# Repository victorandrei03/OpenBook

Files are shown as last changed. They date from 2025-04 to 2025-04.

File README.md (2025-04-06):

# OpenBook - 331CC Preda Victor-Andrei

## 📋 Descriere Proiect
Acest proiect reprezintă o placă electronică (e-board) customizată, proiectată în Autodesk Fusion 360. Include:
- Schematică completă
- Design PCB
- Design 3D al carcasei
- Listă completă de componente (BOM)

## 🗂️ Diagrama bloc



## 🛠️ Componente Cheie
| Componentă | Model | Descriere |
|---|---|---|
| **Microcontroler** | ESP32-C6-WROOM-1-N8 | MCU principal cu WiFi/Bluetooth LE |
| **Ceas RTC** | DS3231SN# | Ceas în timp real cu compensare de temperatură |
| **Senzori** | BME680 | Senzor ambiental (temperatură, umiditate, presiune, VOC) |
| **Management Power** | BD5229G-TR + MCP73831 | Sistem complet de încărcare baterii |

## 📊 Bill of Materials (BOM)

### 🔌 Conectori & Interfețe
| Part Name | Device | Link |
|---|---|---|
| J1 | FH34SRJ-24S-0.5SH_99_ | [Datasheet](https://componentsearchengine.com/part-view/XC6220A331MR-G/Torex) |
| J2 | USB4110-GF-A | [Mouser](https://componentsearchengine.com/part-view/USB4110-GF-A/GCT) |
| J3 | QWIIC_CONNECTORJS-1MM | [SparkFun](https://www.sparkfun.com/products/14417) |

### 💾 Memorie & Storage
| Part Name | Device | Link |
|---|---|---|
| U1 | W25Q512JVEIQ | [Winbond](https://www.snapeda.com/parts/W25Q512JVEIQ/Winbond+Electronics/view-part/) |

### ⚡ Power Management
| Part Name | Device | Link |
|---|---|---|
| IC1 | BD5229G-TR | [ROHM](https://componentsearchengine.com/part-view/BD5229G-TR/ROHM) |
| U4 | MAX17048G+T10 | [Analog Devices](https://www.snapeda.com/parts/MAX17048G+T10/Analog+Devices/view-part/) |

### 🎚️ Componente Pasive
| Categorie | Qty | Device | Link |
|---|-----|---|---|
| **Rezistoare** | 25+ | RR0402 100K | [YAGEO](https://componentsearchengine.com/part-view/R0402%201%25%20100%20K/YAGEO) |
| **Condensatoare** | 20+ | CC0402 1µF | [YAGEO](https://componentsearchengine.com/part-view/CC0402MRX5R5BB106/YAGEO) |
| **Inductoare** | 1 | 744043680 | [Würth](https://eu.mouser.com/ProductDetail/Wurth-Elektronik/744043680) |

### 🛑 Protecții & Diodes
| Part Name | Device | Link |
|---|---|---|
| D1 | USBLC6-2SC6Y | [STMicro](https://www.snapeda.com/parts/USBLC6-2SC6Y/STMicroelectronics/view-part/) |
| D3-D5 | MBR0530 | [Mouser](https://eu.mouser.com/ProductDetail/KYOCERA-AVX/SD0805S020S1R0) |

## 🛠️ Descriere Hardware Detaliată

### 1. Microcontroller - ESP32-C6-WROOM-1-N8
**Specificații Avansate:**
- **Arhitectură:** RISC-V single-core cu 160MHz (configurabil dinamic)
- **Memorie:**
  - 320KB SRAM intern (pentru date)
  - 512KB ROM (pentru bootloader)
  - 8MB Flash SPI (W25Q512JVEIQ) - stochează firmware și date utilizator
- **Conectivitate:**
  - **WiFi 6** (802.11ax) cu throughput de până la 300Mbps
  - **Bluetooth 5 LE** cu support Mesh
  - **Zigbee 3.0** pentru IoT industrial
- **Periferice Integrate:**
  - 4× controller SPI (inclusiv Quad-SPI)
  - 2× I²C (software configurable)
  - 2× UART (cu flow control hardware)
  - 1× USB 2.0 OTG Full-Speed

**Management Energie:**
- **Moduri de operare:**
  - Active Mode: 80mA @ 160MHz
  - Light Sleep: 1.5mA (perif. RAM păstrate)
  - Deep Sleep: 20µA (doar RTC activ)
- **Feature-uri speciale:**
  - Wake-up din Deep Sleep prin:
    - GPIO
    - Timer RTC
    - UART
    - Senzor BME680 (via interrupt)
   
---

### 2. Sistem de Alimentare

**Componente Cheie:**
1. **MCP73831**
   - Curent de încărcare programabil: 100-500mA
   - Protecții integrate: Over-voltage, Reverse discharge
   - LED indicator de stare (conectat la GPIO18)

2. **BD5229G-TR**
   - Eficiență 92% @ 500mA load
   - Ripple voltage < 50mV
   - Shutdown current < 1µA

3. **MAX17048G+T10**
   - Precizie măsurare: ±1% SOC
   - Alertă baterie critică (conectat la GPIO15)
   - Consum propriu: 7µA în mod normal

---

### 3. Senzori & Periferice

#### 3.1 Senzor Environmental BME680
**Interfață:** I²C @ 400kHz (adresă 0x76)  
**Caracteristici unice:**
- **Algoritm BSEC** pentru calcul IAQ (Indice Calitate Aer)
- **Compensare automată** a variațiilor de temperatură
- **Calibrare în fabrică** pentru precizie ridicată

**Conexiuni:**
| Pin BME680 | Pin ESP32 | Notă |
|---|---|---|
| VDD | 3.3V | Alimentare filtrată |
| GND | GND | - |
| SDA | GPIO1 | Cu pull-up 4.7kΩ |
| SCL | GPIO2 | Cu pull-up 4.7kΩ |

#### 3.2 Real-Time Clock DS3231SN#
**Precizie:** ±2ppm (echiv. ~1min/an)  
**Backup:** Supercondensator CPH3225A (10F @ 3.3V)  
**Funcționalități:**
- Alarmă programabilă
- Output square wave (1Hz-32kHz)
- Temperatură internă compensată

---

### 4. Interfețe Externe

#### 4.1 Port USB-C
**Implementare:**
- **Controler:** USB PHY integrat în ESP32-C6
- **Protecții:**
  - ESD: USBLC6-2SC6Y (8kV IEC61000-4-2)
  - Current limit: Polyfuse 500mA

**Funcționalități:**
1. Încărcare baterie
2. Serial Console (CDC-ACM)
3. Update firmware (DFU mode)

#### 4.2 Conector Qwiic
**Aplicații:**
- Conectare senzori adiționali
- Debug I²C bus
- Extensii custom

---

## 🔌 Mapare Pini ESP32-C6

| Pin ESP32-C6 | Componentă / Semnal | Motivul Alegerii |
|---|---|---|
| **GPIO1 (SDA)** | Magistrală I²C (BME680, MAX17048, DS3231) | Permite comunicarea simultană cu multiple dispozitive prin protocol standard |
| **GPIO2 (SCL)** | Semnal de sincronizare I²C | Asigură temporizarea corectă a transferurilor pe magistrala shared I²C |
| **GPIO5** | SPI MISO (E-Paper) | Facilitatează recepția datelor de stare de la display |
| **GPIO6** | SPI MOSI (E-Paper) | Canal dedicat pentru transmiterea imaginilor către ecran |
| **GPIO7** | SPI CLK (E-Paper) | Generează semnalul de ceas pentru sincronizarea datelor SPI |
| **GPIO8** | SPI CS (E-Paper) | Selectează exclusiv display-ul în configurații multi-slave |
| **GPIO9** | E-Paper DC | Determină dacă transferul conține date sau comenzi |
| **GPIO10** | E-Paper RST | Permite resetarea hardware a display-ului în caz de eroare |
| **GPIO11** | E-Paper BUSY | Monitorizează starea de ocupat pentru sincronizare fără polling |
| **GPIO12** | BUTTON_BOOT | Configurat special pentru intrare în modul de programare |
| **GPIO13** | BUTTON_RESET | Asigură resetarea controlată a sistemului |
| **GPIO14** | BUTTON_USER | Permite interacțiunea utilizatorului cu meniul principal |
| **GPIO15** | MAX17048 ALERT | Semnalează stări critice ale bateriei prin interrupt |
| **GPIO16** | USB D+ | Implementare directă a fizicului USB conform specificației |
| **GPIO17** | USB D- | Pereche diferențială obligatorie pentru comunicarea USB |
| **GPIO18** | STATUS_LED | Oferă feedback vizual despre starea sistemului |
| **GPIO19** | SD Card CS | Selectează cardul SD în arhitectura SPI shared |
| **GPIO20** | SD Card MISO | Primește date de la memoria externă |
| **GPIO21** | SD Card MOSI | Transmite comenzi și date către cardul SD |
| **GPIO4** | SD Card CLK | Asigură sincronizarea transferurilor SPI către/storage |

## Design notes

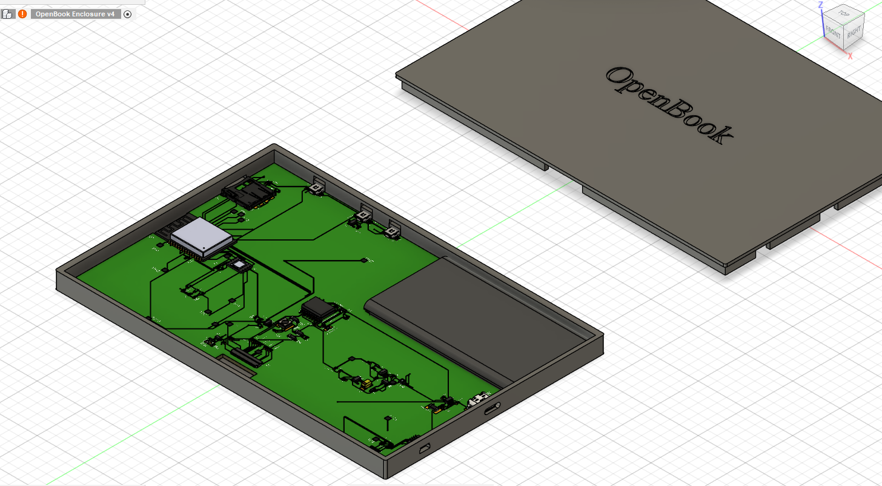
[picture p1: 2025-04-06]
Images/openbook_3D.png

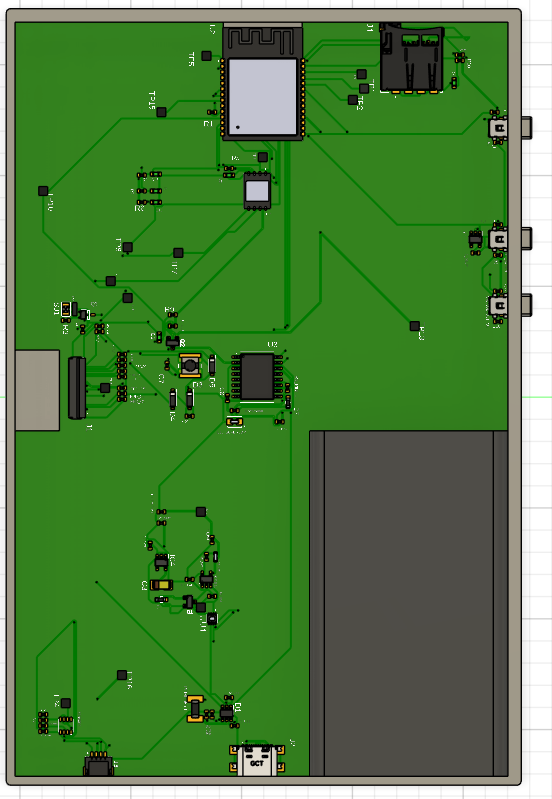
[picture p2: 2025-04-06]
Images/openbook_top.png

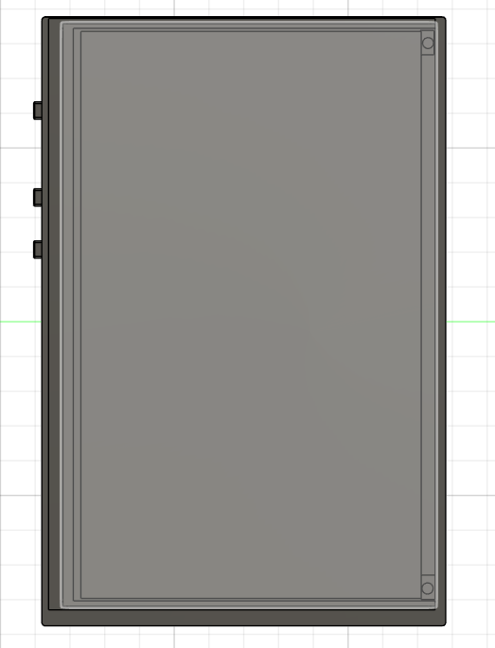
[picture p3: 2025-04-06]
Images/openbook_bot.png

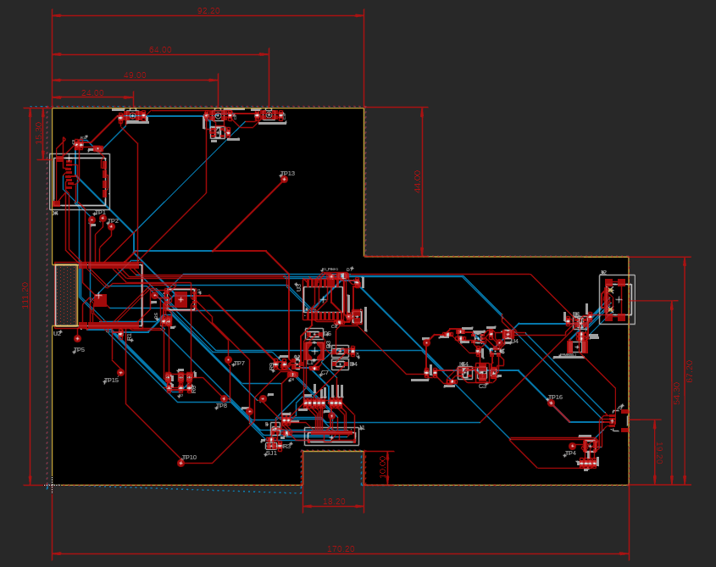
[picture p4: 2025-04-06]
Images/PCB.png

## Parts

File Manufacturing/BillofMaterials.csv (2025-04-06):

Qty | Value | Device | Package | Parts | Description | ARROW_PART_NUMBER | ARROW_PRICE-STOCK | AVAILABILITY | CENTROID_NOT_SPECIFIED | CHECK_PRICES | COPYRIGHT | DATASHEET | DESCRIPTION | DIGIKEY_DESCRIPTION | DIGIKEY_PART_NUMBER | HEIGHT | LEAD_FREE | MANUFACTURER_NAME | MANUFACTURER_PART_NUMBER | MF | MFR_NAME | MOUSER_PART_NUMBER | MOUSER_PRICE-STOCK | MOUSER_TESTING_PART_NUMBER | MOUSER_TESTING_PRICE-STOCK | MP | MPN | PACKAGE | POPULARITY | PREFIX | PRICE | PROD_ID | PURCHASE-URL | ROHS | SNAPEDA_LINK | SPICEMODEL | SPICEPREFIX | TEMPERATURE_RANGE_HIGH | TEMPERATURE_RANGE_LOW | TP_SIGNAL_NAME | VALUE
1 |  | ADAFRUIT_LEDCHIP-LED0603 | ADAFRUIT_CHIP-LED0603 | CHG_LED | LED
1 |  | SJ | SJ | SJ1 | SMD solder JUMPER |  |  |  |  |  |  |  |  |  |  |  |  |  |  |  |  |  |  |  |  |  |  |  | 3
1 | 0.1uF/50V | EAGLE-LTSPICE_CC0402 | EAGLE-LTSPICE_C0402 | EPD_C5 | CAPACITOR, European symbol |  |  |  |  |  |  |  |  |  |  |  |  |  |  |  |  |  |  |  |  |  |  |  |  |  |  |  |  |  |  | NONE | C
1 | 0.47 | ESP32_WROVER_EAGLE-LTSPICE_RR0402 | ESP32_WROVER_EAGLE-LTSPICE_R0402 | R3 | RESISTOR, European symbol |  |  |  |  |  |  |  |  |  |  |  |  |  |  |  |  |  |  |  |  |  |  |  |  |  |  |  |  |  |  | NONE | R
8 | 100nF | EAGLE-LTSPICE_CC0402 | EAGLE-LTSPICE_C0402 | C1, C2, C4_USB, C6, C8, C9, C10, C_DELAY | CAPACITOR, European symbol |  |  |  |  |  |  |  |  |  |  |  |  |  |  |  |  |  |  |  |  |  |  |  |  |  |  |  |  |  |  | NONE | C
1 | 100uF | RCL_CPOL-EUCT3528 | RCL_CT3528 | C3 | POLARIZED CAPACITOR, European symbol |  |  |  |  |  |  |  |  |  |  |  |  |  |  |  |  |  |  |  |  |  |  |  | 0 |  |  |  |  |  |  |  | C
16 | 10K | ESP32_WROVER_EAGLE-LTSPICE_RR0402 | ESP32_WROVER_EAGLE-LTSPICE_R0402 | R1_PINH, R1_PINH1, R1_PWRUSB, R2_PINH, R2_PINH1, R4, R5, R6, R7, R8, R9, R10, R_BOOT, R_CHANGE, R_CL1, R_RESET | RESISTOR, European symbol |  |  |  |  |  |  |  |  |  |  |  |  |  |  |  |  |  |  |  |  |  |  |  |  |  |  |  |  |  |  | NONE | R
1 | 10k | ESP32_WROVER_EAGLE-LTSPICE_RR0402 | ESP32_WROVER_EAGLE-LTSPICE_R0402 | R1 | RESISTOR, European symbol |  |  |  |  |  |  |  |  |  |  |  |  |  |  |  |  |  |  |  |  |  |  |  |  |  |  |  |  |  |  | NONE | R
1 | 10uF | ESP32_WROVER_EAGLE-LTSPICE_CC0402 | ESP32_WROVER_EAGLE-LTSPICE_C0402 | C7 | CAPACITOR, European symbol |  |  |  |  |  |  |  |  |  |  |  |  |  |  |  |  |  |  |  |  |  |  |  |  |  |  |  |  |  |  | NONE | C
1 | 112A-TAAR-R03_ATTEND | 112A-TAAR-R03_ATTEND | 112ATAARR03ATTEND | J4 | Micro SD Card Socket, Push-Push Type, Top Mount, SMT, H=1.83mm, 10u |  |  |  |  |  |  |  | Micro SD Card Socket | Push-Push Type | Top Mount | SMT | H=1.83mm | 10u |  |  | 1.9mm |  | ATTEND | 112A-TAAR-R03 ATTEND
1 | 15 | ESP32_WROVER_EAGLE-LTSPICE_RR0402 | ESP32_WROVER_EAGLE-LTSPICE_R0402 | R_CAPACITOR | RESISTOR, European symbol |  |  |  |  |  |  |  |  |  |  |  |  |  |  |  |  |  |  |  |  |  |  |  |  |  |  |  |  |  |  | NONE | R
1 | 1uF | EAGLE-LTSPICE_CC0402 | EAGLE-LTSPICE_C0402 | C5 | CAPACITOR, European symbol |  |  |  |  |  |  |  |  |  |  |  |  |  |  |  |  |  |  |  |  |  |  |  |  |  |  |  |  |  |  | NONE | C
9 | 1uF/50V | EAGLE-LTSPICE_CC0402 | EAGLE-LTSPICE_C0402 | EPD_C1, EPD_C2, EPD_C6, EPD_C7, EPD_C8, EPD_C9, EPD_C10, EPD_C11, EPD_C12 | CAPACITOR, European symbol |  |  |  |  |  |  |  |  |  |  |  |  |  |  |  |  |  |  |  |  |  |  |  |  |  |  |  |  |  |  | NONE | C
1 | 2.2 | ESP32_WROVER_EAGLE-LTSPICE_RR0402 | ESP32_WROVER_EAGLE-LTSPICE_R0402 | R2 | RESISTOR, European symbol |  |  |  |  |  |  |  |  |  |  |  |  |  |  |  |  |  |  |  |  |  |  |  |  |  |  |  |  |  |  | NONE | R
1 | 200 | ESP32_WROVER_EAGLE-LTSPICE_RR0402 | ESP32_WROVER_EAGLE-LTSPICE_R0402 | R1_BAT | RESISTOR, European symbol |  |  |  |  |  |  |  |  |  |  |  |  |  |  |  |  |  |  |  |  |  |  |  |  |  |  |  |  |  |  | NONE | R
2 | 20V/4.2A/52mO/1.4W | ESP32_WROVER_SPARKFUN-DISCRETESEMI_MOSFET_PCH-DMG2305UX-7 | ESP32_WROVER_SPARKFUN-DISCRETESEMI_SOT23-3 | Q1, Q2 | P-channel MOSFETs |  |  |  |  |  |  |  |  |  |  |  |  |  |  |  |  |  |  |  |  |  |  |  |  |  |  | TRAN-14388 |  |  |  |  |  |  |  |  | 20V/4.2A/52mO/1.4W
1 | 2k | ESP32_WROVER_EAGLE-LTSPICE_RR0402 | ESP32_WROVER_EAGLE-LTSPICE_R0402 | R2_BAT | RESISTOR, European symbol |  |  |  |  |  |  |  |  |  |  |  |  |  |  |  |  |  |  |  |  |  |  |  |  |  |  |  |  |  |  | NONE | R
2 | 4.7uF | EAGLE-LTSPICE_CC0402 | EAGLE-LTSPICE_C0402 | C2_BAT, C5_USB | CAPACITOR, European symbol |  |  |  |  |  |  |  |  |  |  |  |  |  |  |  |  |  |  |  |  |  |  |  |  |  |  |  |  |  |  | NONE | C
3 | 4.7uF | ESP32_WROVER_EAGLE-LTSPICE_CC0402 | ESP32_WROVER_EAGLE-LTSPICE_C0402 | C1_BAT, C1_BAT1, C1_BAT2 | CAPACITOR, European symbol |  |  |  |  |  |  |  |  |  |  |  |  |  |  |  |  |  |  |  |  |  |  |  |  |  |  |  |  |  |  | NONE | C
1 | 4.7uF/25V | ESP32_WROVER_EAGLE-LTSPICE_CC0402 | ESP32_WROVER_EAGLE-LTSPICE_C0402 | C4 | CAPACITOR, European symbol |  |  |  |  |  |  |  |  |  |  |  |  |  |  |  |  |  |  |  |  |  |  |  |  |  |  |  |  |  |  | NONE | C
2 | 5k1 | ESP32_WROVER_EAGLE-LTSPICE_RR0402 | ESP32_WROVER_EAGLE-LTSPICE_R0402 | R2-USB, R2-USB1 | RESISTOR, European symbol |  |  |  |  |  |  |  |  |  |  |  |  |  |  |  |  |  |  |  |  |  |  |  |  |  |  |  |  |  |  | NONE | R
1 | 68uH | 744043680IND_4828-WE-TPC_WRE | IND_4828-WE-TPC_WRE | L1 |  |  |  |  |  |  | Copyright (C) 2024 Ultra Librarian. All rights reserved. |  |  |  |  |  |  |  | 744043680 |  | Wurth Electronics
1 | BD5229G-TR | BD5229G-TR | SOT95P280X125-5N | IC1 | Voltage Detector with Adjustable Delay Time: CMOS processes are utilized to develop high precision, low current consumption CMOS reset ICs that allow arbitrary setting of the delay time. The extensive lineup includes both Nch Open Drain and CMOS output types in a wide range of detection voltages (from 2.3V to 6.0V, in 0.1V steps), enabling selection of the ideal solution based on customer requirements. In addition, the entire series is of course both lead-free and RoHS-compliant. |  |  |  |  |  |  |  | Voltage Detector with Adjustable Delay Time: CMOS processes are utilized to develop high precision | low current consumption CMOS reset ICs that allow arbitrary setting of the delay time. The extensive lineup includes both Nch Open Drain and CMOS output types in a wide range of detection voltages (from 2.3V to 6.0V | in 0.1V steps) | enabling selection of the ideal solution based on customer requirements. In addition | the entire series is of course both lead-free and RoHS-compliant. |  |  | 1.25mm |  | ROHM Semiconductor | BD5229G-TR |  |  | 755-BD5229G-TR | https://www.mouser.co.uk/ProductDetail/ROHM-Semiconductor/BD5229G-TR?qs=4kLU8WoGk0vvnhrrYwdszw%3D%3D
3 | BUTTON_CUSYOMV1 | BUTTON_CUSYOMV1 | MYBUTTON | BOOT_BUTTON1, CHANGE_BUTTON, RESET_BUTTON
1 | CPH3225A | CPH3225A | CAPCP3225X100N | C10_SUPERCAP | Cap 0.011F 3.3V 1210 Flat Check availability |  |  | Not in stock |  | https://www.snapeda.com/parts/CPH3225A/Seiko+Instruments/view-part/?ref=eda |  |  | 11 mF (EDLC) Supercapacitor 3.3 V 1210 (3225 Metric) - - |  |  |  |  |  |  | Seiko Instruments |  |  |  |  |  | CPH3225A |  | 1210 Seiko |  |  | None |  | https://www.snapeda.com/api/url_track_click_mouser/?unipart_id=562593&manufacturer=Seiko Instruments&part_name=CPH3225A&search_term=None |  | https://www.snapeda.com/parts/CPH3225A/Seiko+Instruments/view-part/?ref=snap
1 | DS3231SN# | DS3231SN# | SOIC127P1032X265-16N | U3 | Real Time Clock Serial 16-Pin SOIC W T/R Check availability |  |  | In Stock |  | https://www.snapeda.com/parts/DS3231SN%23/Analog+Devices/view-part/?ref=eda |  |  | Extremely Accurate I²C-Integrated RTC/TCXO/Crystal |  |  |  |  |  |  | Analog Devices |  |  |  |  |  | DS3231SN# |  | SOIC-16 Maxim |  |  | None |  | https://www.snapeda.com/api/url_track_click_mouser/?unipart_id=99048&manufacturer=Analog Devices&part_name=DS3231SN#&search_term=None |  | https://www.snapeda.com/parts/DS3231SN%23/Analog+Devices/view-part/?ref=snap
1 | ESP32-C6-WROOM-1-N8 | ESP32-C6-WROOM-1-N8 | XCVR_ESP32-C6-WROOM-1-N8 | U2 | Check availability |  |  | In Stock |  | https://www.snapeda.com/parts/ESP32-C6-WROOM-1-N8/Espressif+Systems/view-part/?ref=eda |  |  | Multiprotocol Modules ESP32-C6 module | Wi-Fi 6 in 2.4 GHz band | Bluetooth 5 | Zigbee 3.0 and Thread. ESP34-WROOM Compatible - ENGINEERING SAMPLE |  |  |  |  |  |  | Espressif Systems |  |  |  |  |  | ESP32-C6-WROOM-1-N8 |  | None |  |  | None |  |  |  | https://www.snapeda.com/parts/ESP32-C6-WROOM-1-N8/Espressif+Systems/view-part/?ref=snap
1 | ESP32C6_VARISTORCN1812 | ESP32C6_VARISTORCN1812 | ESP32C6_VARISTOR_CT/CN1812 | PFMF.050.1 | VARISTOR |  |  |  |  |  |  |  |  |  |  |  |  |  |  |  |  |  |  |  |  |  |  |  | 0
2 | ESP32_WROVER_AVX---SD0805S020S1R0_AVX_SD0805S020S1R0_0_0AVX_SD0805S020S1R0_0_0 | ESP32_WROVER_AVX---SD0805S020S1R0_AVX_SD0805S020S1R0_0_0AVX_SD0805S020S1R0_0_0 | ESP32_WROVER_AVX---SD0805S020S1R0_AVX_SD0805S020S1R0_0 | D2, D7 | Schottky Barrier Rectifier Diode |  |  |  | No |  |  | http://datasheets.avx.com/schottky.pdf |  | DIODE SCHOTTKY 20V 1A 0805 | 478-7800-1-ND |  | yes |  |  | AVX |  | 581-SD0805S020S1R0 |  |  |  |  |  | 0805 (2012 metric) |  | D |  |  |  | yes |  |  |  | +125°C | -55°C
1 | ESP32_WROVER_BME680_BME680 | ESP32_WROVER_BME680_BME680 | ESP32_WROVER_BME680_PSON80P300X300X100-8N | SENSOR2 | Integrated Environmental Unit |  |  | Unavailable |  |  |  |  | Integrated Environmental Unit |  |  |  |  |  |  | Bosch Sensortec |  |  |  |  |  | BME680 |  | LGA-8 Bosch Tools |  |  | None
1 | ESP32_WROVER_SPARKFUN-IC-POWER_MCP73831 | ESP32_WROVER_SPARKFUN-IC-POWER_MCP73831 | ESP32_WROVER_SPARKFUN-IC-POWER_SOT23-5 | MCP73831 | MCP73831T Li-Ion, Li-Pol Controller |  |  |  |  |  |  |  |  |  |  |  |  |  |  |  |  |  |  |  |  |  |  |  |  |  |  | IC-09995
1 | FH34SRJ-24S-0.5SH_99_ | FH34SRJ-24S-0.5SH_99_ | FH34SRJ24S05SH99 | J1 | (0.50mm) Surface Mount, Right Angle |  |  |  |  |  |  |  | 24 Position FFC | FPC Connector Contacts | (0.50mm) Surface Mount | Right Angle |  |  | 1.1mm |  | Hirose | FH34SRJ-24S-0.5SH(99) |  |  | 798-FH34SRJ24S05SH99 | https://www.mouser.co.uk/ProductDetail/Hirose-Connector/FH34SRJ-24S-0.5SH99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
1 | MAX17048G+T10 | MAX17048G+T10 | SON50P200X200X80-9N | U4 | Check availability |  |  | In Stock |  | https://www.snapeda.com/parts/MAX17048G+T10/Analog+Devices/view-part/?ref=eda |  |  | 3µA 1-Cell/2-Cell Fuel Gauge with ModelGauge |  |  |  |  |  |  | Analog Devices |  |  |  |  |  | MAX17048G+T10 |  | TDFN-8 Maxim |  |  | None |  | https://www.snapeda.com/api/url_track_click_mouser/?unipart_id=329239&manufacturer=Analog Devices&part_name=MAX17048G+T10&search_term=None |  | https://www.snapeda.com/parts/MAX17048G+T10/Analog+Devices/view-part/?ref=snap
3 | MBR0530 | MBR0530 | SOD3716X135N | D3, D4, D5 | ON SEMICONDUCTOR - MBR0530 - DIODE, SCHOTTKY, 0.5A, 30V, SOD-123 |  |  | In Stock |  | https://www.snapeda.com/parts/MBR0530/Onsemi/view-part/?ref=eda |  |  | Diode Schottky 30 V 500mA Surface Mount SOD-123 |  |  |  |  |  |  | ON Semiconductor |  |  |  |  |  | MBR0530 |  | SOD-123-2 ON Semiconductor |  |  | None |  | https://www.snapeda.com/api/url_track_click_mouser/?unipart_id=179458&manufacturer=ON Semiconductor&part_name=MBR0530&search_term=None |  | https://www.snapeda.com/parts/MBR0530/Onsemi/view-part/?ref=snap
6 | PGB1010603MR | PGB1010603MR | DIOC1608X36N | D6, D8, D9, D10, D11, D12 | Check availability |  |  | In Stock |  | https://www.snapeda.com/parts/PGB1010603MR/Littelfuse/view-part/?ref=eda |  |  | 150V (Typ) Clamp - Ipp Tvs Diode Surface Mount 0603 (1608 Metric) |  |  |  |  |  |  | Littelfuse Inc. |  |  |  |  |  | PGB1010603MR |  | 0603 Littelfuse Inc. |  |  | None |  | https://www.snapeda.com/api/url_track_click_mouser/?unipart_id=5659453&manufacturer=Littelfuse Inc.&part_name=PGB1010603MR&search_term=None |  | https://www.snapeda.com/parts/PGB1010603MR/Littelfuse/view-part/?ref=snap
1 | QWIIC_RIGHT_ANGLE | QWIIC_CONNECTORJS-1MM | JST04_1MM_RA | J3 | SparkFun I2C Standard Qwiic Connector |  |  |  |  |  |  |  |  |  |  |  |  |  |  |  |  |  |  |  |  |  |  |  |  |  |  | CONN-13694 |  |  |  |  |  |  |  |  | QWIIC_RIGHT_ANGLE
1 | SAMACSYS_PARTS_USB4110-GF-A | SAMACSYS_PARTS_USB4110-GF-A | SAMACSYS_PARTS_USB4110GFA | J2 | CONN USB 2.0 TYPE-C R/A SMT |  |  |  |  |  |  |  | CONN USB 2.0 TYPE-C R/A SMT |  |  | 3.26mm |  | GCT (GLOBAL CONNECTOR TECHNOLOGY) | USB4110-GF-A |  |  | 640-USB4110-GF-A | https://www.mouser.co.uk/ProductDetail/GCT/USB4110-GF-A?qs=KUoIvG%2F9IlYiZvIXQjyJeA%3D%3D
1 | SI1308EDL-T1-GE3 | SI1308EDL-T1-GE3 | SOT65P210X110-3N | Q3 | MOSFET N-Ch 30V 1.5A TrenchFET SC70 Vishay Si1308EDL-T1-GE3 N-channel MOSFET Transistor, 1.5 A, 30 V, 3-Pin SC-70 |  |  | In Stock |  | https://www.snapeda.com/parts/SI1308EDL-T1-GE3/Vishay+Siliconix/view-part/?ref=eda |  |  | Si1308EDL-T1-GE3 N-channel MOSFET Transistor | 1.5 A | 30 V | 3-Pin SC-70 | Siliconix / Vishay SI1308EDL-T1-GE3 |  |  |  |  |  |  | Vishay Siliconix |  |  |  |  |  | SI1308EDL-T1-GE3 |  | SOT-323 Vishay Semiconductor |  |  | None |  | https://www.snapeda.com/api/url_track_click_mouser/?unipart_id=274603&manufacturer=Vishay Siliconix&part_name=SI1308EDL-T1-GE3&search_term=None |  | https://www.snapeda.com/parts/SI1308EDL-T1-GE3/Vishay+Siliconix/view-part/?ref=snap
17 | TPTP20R | TPTP20R | TP20R | TP1, TP2, TP3, TP4, TP5, TP6, TP7, TP8, TP9, TP10, TP11, TP12, TP13, TP14, TP15, TP16, TP17 | Test pad |  |  |  |  |  |  |  |  |  |  |  |  |  |  |  |  |  |  |  |  |  |  |  | 2
1 | USBLC6-2SC6Y | USBLC6-2SC6Y | SOT95P280X145-6N | D1 | Low Cap. ESD Protection Auto SOT-23-6 STMicroelectronics USBLC6-2SC6Y, Dual Uni-Directional TVS Diode Array, 6-Pin SOT-23 |  |  | In Stock |  | https://www.snapeda.com/parts/USBLC6-2SC6Y/STMicroelectronics/view-part/?ref=eda |  |  | 17V Clamp 5A (8/20µs) Ipp Tvs Diode Surface Mount SOT-23-6 |  |  |  |  |  |  | STMicroelectronics |  |  |  |  |  | USBLC6-2SC6Y |  | SOT-23-6 STMicroelectronics |  |  | None |  |  |  | https://www.snapeda.com/parts/USBLC6-2SC6Y/STMicroelectronics/view-part/?ref=snap
1 | W25Q512JVEIQ | W25Q512JVEIQ | SON127P600X800X80-9N | U1 | Check availability |  |  | In Stock |  | https://www.snapeda.com/parts/W25Q512JVEIQ/Winbond+Electronics/view-part/?ref=eda |  |  | FLASH - NOR Memory IC 512Mb (64M x 8) SPI - Quad I/O 133 MHz 8-WSON (8x6) |  |  |  |  |  |  | Winbond Electronics |  |  |  |  |  | W25Q512JVEIQ |  | Package |  |  | None |  |  |  | https://www.snapeda.com/parts/W25Q512JVEIQ/Winbond+Electronics/view-part/?ref=snap
1 | XC6220A331MR-G | XC6220A331MR-G | SOT95P280X120-5N | IC4 | LDO Voltage Regulators |  |  |  |  |  |  |  | LDO Voltage Regulators |  |  | 1.2mm |  | Torex | XC6220A331MR-G |  |  | 865-XC6220A331MR-G | https://www.mouser.co.uk/ProductDetail/Torex-Semiconductor/XC6220A331MR-G?qs=AsjdqWjXhJ8ZSWznL1J0gg%3D%3D

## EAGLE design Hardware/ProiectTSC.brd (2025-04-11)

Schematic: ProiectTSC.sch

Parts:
BOOT_BUTTON1: BUTTON_CUSYOMV1; MYBUTTON
C1, C2, C4_USB, C6, C8, C9, C10: 100nF; EAGLE-LTSPICE_C0402
C1_BAT, C1_BAT1, C1_BAT2: 4.7uF; ESP32_WROVER_EAGLE-LTSPICE_C0402
C2_BAT, C5_USB: 4.7uF; EAGLE-LTSPICE_C0402
C3: 100uF; RCL_CT3528
C4: 4.7uF/25V; ESP32_WROVER_EAGLE-LTSPICE_C0402
C5: 1uF; EAGLE-LTSPICE_C0402
C7: 10uF; ESP32_WROVER_EAGLE-LTSPICE_C0402
C10_SUPERCAP: CPH3225A; CAPCP3225X100N
CHANGE_BUTTON: BUTTON_CUSYOMV1; MYBUTTON
CHG_LED: ADAFRUIT_LEDCHIP-LED0603; ADAFRUIT_CHIP-LED0603
C_DELAY: 100nF; EAGLE-LTSPICE_C0402
D1: USBLC6-2SC6Y; SOT95P280X145-6N
D2, D7: ESP32_WROVER_AVX---SD0805S020S1R0_AVX_SD0805S020S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; ESP32_WROVER_AVX---SD0805S020S1R0_AVX_SD0805S020S1R0_0
D3, D4, D5: MBR0530; SOD3716X135N
D6, D8, D9, D10, D11, D12: PGB1010603MR; DIOC1608X36N
EPD_C1, EPD_C2, EPD_C6, EPD_C7, EPD_C8, EPD_C9, EPD_C10, EPD_C11, EPD_C12: 1uF/50V; EAGLE-LTSPICE_C0402
EPD_C5: 0.1uF/50V; EAGLE-LTSPICE_C0402
IC1: BD5229G-TR; SOT95P280X125-5N
IC4: XC6220A331MR-G; SOT95P280X120-5N
J1: FH34SRJ-24S-0.5SH_99_; FH34SRJ24S05SH99
J2: SAMACSYS_PARTS_USB4110-GF-A; SAMACSYS_PARTS_USB4110GFA
J3: QWIIC_RIGHT_ANGLE; JST04_1MM_RA
J4: 112A-TAAR-R03_ATTEND; 112ATAARR03ATTEND
L1: 68uH; IND_4828-WE-TPC_WRE
MCP73831: ESP32_WROVER_SPARKFUN-IC-POWER_MCP73831; ESP32_WROVER_SPARKFUN-IC-POWER_SOT23-5
PFMF.050.1: ESP32C6_VARISTORCN1812; ESP32C6_VARISTOR_CT/CN1812
Q1, Q2: 20V/4.2A/52mΩ/1.4W; ESP32_WROVER_SPARKFUN-DISCRETESEMI_SOT23-3
Q3: SI1308EDL-T1-GE3; SOT65P210X110-3N
R1: 10k; ESP32_WROVER_EAGLE-LTSPICE_R0402
R1_BAT: 200; ESP32_WROVER_EAGLE-LTSPICE_R0402
R1_PINH, R1_PINH1, R1_PWRUSB, R2_PINH, R2_PINH1, R4, R5, R6, R7, R8, R9, R10: 10K; ESP32_WROVER_EAGLE-LTSPICE_R0402
R2: 2.2; ESP32_WROVER_EAGLE-LTSPICE_R0402
R2-USB, R2-USB1: 5k1; ESP32_WROVER_EAGLE-LTSPICE_R0402
R2_BAT: 2k; ESP32_WROVER_EAGLE-LTSPICE_R0402
R3: 0.47; ESP32_WROVER_EAGLE-LTSPICE_R0402
RESET_BUTTON: BUTTON_CUSYOMV1; MYBUTTON
R_BOOT: 10K; ESP32_WROVER_EAGLE-LTSPICE_R0402
R_CAPACITOR: 15; ESP32_WROVER_EAGLE-LTSPICE_R0402
R_CHANGE: 10K; ESP32_WROVER_EAGLE-LTSPICE_R0402
R_CL1: 10K; ESP32_WROVER_EAGLE-LTSPICE_R0402
R_RESET: 10K; ESP32_WROVER_EAGLE-LTSPICE_R0402
SENSOR2: ESP32_WROVER_BME680_BME680; ESP32_WROVER_BME680_PSON80P300X300X100-8N
SJ1: SJ
TP3, TP6, TP14: TPTP20R; TP20R
TP_3V3: TPTP20R; TP20R
TP_EPD_3V3, TP_EPD_3V3_C: TPTP20R; TP20R
TP_EPD_BUSY: TPTP20R; TP20R
TP_EPD_CS: TPTP20R; TP20R
TP_EPD_DC: TPTP20R; TP20R
TP_EPD_RST: TPTP20R; TP20R
TP_GND, TP_GND1: TPTP20R; TP20R
TP_INT_RT: TPTP20R; TP20R
TP_MOSI: TPTP20R; TP20R
TP_RX: TPTP20R; TP20R
TP_SCK: TPTP20R; TP20R
TP_TX: TPTP20R; TP20R
U1: W25Q512JVEIQ; SON127P600X800X80-9N
U2: ESP32-C6-WROOM-1-N8; XCVR_ESP32-C6-WROOM-1-N8
U3: DS3231SN#; SOIC127P1032X265-16N
U4: MAX17048G+T10; SON50P200X200X80-9N

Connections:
3V3: C1_BAT2.1, C3.+, C9.1, D7.2 (ANODE), IC1.2 (VDD), IC4.5 (VOUT), J3.2, J4.P4 (VDD), Q2.3 (D), R1.2, R1_PINH1.2, R2_PINH1.2, R5.2, R6.2, R7.2, R8.2, R9.2, R10.2, R_BOOT.2, R_CHANGE.2, R_CL1.2, R_RESET.2, TP_3V3.TP, U1.3 (!WP!(IO2)), U1.7 (!HOLD!/!RESET!(IO3)), U1.8 (VCC), U2.2 (3V3), U3.2 (VCC)
32KHZ: R2_PINH1.1, U2.9 (IO1), U3.1 (32KHZ)
DN: D1.4 (I/O2_2), J2.A7, J2.B7
DP: D1.6 (I/O1_2), J2.A6, J2.B6
EPD_3V3: C7.1, EPD_C5.1, J1.15, J1.16, L1.2, Q2.2 (S), TP_EPD_3V3.TP
EPD_3V3_C: Q2.1 (G), R_CL1.1, TP_EPD_3V3_C.TP, U2.18 (IO20)
EPD_BUSY: J1.9, TP_EPD_BUSY.TP, U2.26 (IO3)
EPD_CS: D6.2, J1.12, R9.1, TP_EPD_CS.TP, U2.11 (IO10)
EPD_DC: J1.11, TP_EPD_DC.TP, U2.5 (IO5)
EPD_RST: J1.10, TP_EPD_RST.TP, U2.21 (IO23)
FLASH_CS: D9.2, R5.1, U1.1 (!CS), U2.12 (IO11)
GDR: J1.2, Q3.1 (G), R4.2
GND: BOOT_BUTTON1.1, BOOT_BUTTON1.2, C1.2, C1_BAT.2, C1_BAT1.2, C1_BAT2.2, C2.2, C2_BAT.2, C3.-, C4_USB.2, C5.2, C5_USB.2, C6.2, C7.2, C8.2, C9.2, C10.2, C10_SUPERCAP.2, CHANGE_BUTTON.1, CHANGE_BUTTON.2, C_DELAY.2, D1.2 (GND), D3.1 (K), D6.1, D8.1, D9.1, D10.1, D11.1, D12.1, EPD_C1.2, EPD_C2.2, EPD_C5.2, EPD_C6.2, EPD_C7.2, EPD_C8.2, EPD_C9.2, EPD_C10.2, EPD_C11.2, EPD_C12.2, IC1.3 (GND), IC4.2 (VSS), J1.8, J1.17, J1.MP1, J1.MP2, J2.A1, J2.A12, J2.B1, J2.B12, J2.MP1, J2.MP2, J2.MP3, J2.MP4, J3.1, J4.G1 (GND_1), J4.G2 (GND_2), J4.G3 (GND_3), J4.G4 (GND_4), J4.P6 (VSS), MCP73831.2 (VSS), R1_PWRUSB.1, R2.1, R2-USB.2, R2-USB1.1, R2_BAT.1, R4.1, RESET_BUTTON.1, RESET_BUTTON.2, SENSOR2.1 (GND), SENSOR2.5 (SDO), SENSOR2.7 (GND), SJ1.1, TP_GND.TP, TP_GND1.TP, U1.4 (GND), U1.9 (EXP), U2.1 (GND), U2.28 (GND), U2.29_1 (GND), U2.29_2 (GND), U2.29_3 (GND), U2.29_4 (GND), U2.29_5 (GND), U2.29_6 (GND), U2.29_7 (GND), U2.29_8 (GND), U2.29_9 (GND), U3.13 (GND), U4.1 (CTG), U4.4 (GND), U4.6 (QSTRT), U4.9 (EP)
GPIO8: R1.1, U2.10 (IO8)
I2C_PW: R1_PINH.2, R2_PINH.2, SENSOR2.2 (CSB), SENSOR2.6 (VDDIO), SENSOR2.8 (VDD), U2.17 (IO19)
INT_RTC: R1_PINH1.1, TP_INT_RT.TP, U2.8 (IO0), U3.3 (SQW/!INT)
IO/BOOT: BOOT_BUTTON1.3, BOOT_BUTTON1.4, C6.1, R_BOOT.1, U2.15 (IO9)
IO/CHANGE: C10.1, CHANGE_BUTTON.3, CHANGE_BUTTON.4, R_CHANGE.1, U2.23 (IO15)
MISO: D12.2, J4.P7 (DAT0), R8.1, TP6.TP, U1.2 (DO(IO1)), U2.27 (IO2)
MOSI: D11.2, J1.14, J4.P3 (CMD), R7.1, TP_MOSI.TP, U1.5 (DI(IO0)), U2.7 (IO7)
unnamed: J2.A5, R2-USB1.2
unnamed: C1_BAT1.1, D2.1 (CATHODE), IC4.1 (VIN), IC4.3 (CE), Q1.2 (S)
unnamed: J2.B5, R2-USB.1
unnamed: CHG_LED.C, R1_BAT.1
unnamed: C4.1, D3.2 (A), D4.1 (K)
unnamed: MCP73831.1 (STAT), R1_BAT.2
unnamed: EPD_C12.1, J1.24
unnamed: MCP73831.5 (PROG), R2_BAT.2
unnamed: EPD_C1.1, J1.4
unnamed: EPD_C2.1, J1.5
unnamed: EPD_C10.1, J1.22
unnamed: EPD_C8.1, J1.20
unnamed: EPD_C7.1, J1.19
unnamed: EPD_C6.1, J1.18
unnamed: C1.1, C2.1
unnamed: C_DELAY.1, IC1.5 (CT)
unnamed: D7.1 (CATHODE), R_CAPACITOR.1
PREVGH: D5.1 (K), EPD_C9.1, J1.21
PREVGL: D4.2 (A), EPD_C11.1, J1.23
RESE: J1.3, Q3.2 (S), R3.2
RESE': R2.2, R3.1, SJ1.2
RESET: C5.1, IC1.1 (VOUT), RESET_BUTTON.3, RESET_BUTTON.4, R_RESET.1, U2.3 (EN)
RTC_RST: U2.16 (IO18), U3.4 (!RST)
RX: TP_RX.TP, U2.24 (RXD0/GPIO17)
SCK: D10.2, J1.13, J4.P5 (CLK), R6.1, TP_SCK.TP, U1.6 (CLK), U2.6 (IO6)
SCL: J3.4, R2_PINH.1, SENSOR2.4 (SCK), U2.20 (IO22), U3.16 (SCL), U4.7 (SCL)
SDA: J3.3, R1_PINH.1, SENSOR2.3 (SDI), U2.19 (IO21), U3.15 (SDA), U4.8 (SDA)
SRC: C4.2, D5.2 (A), L1.1, Q3.3 (D)
SS_SD: D8.2, J4.P2 (CD/DAT3), R10.1, U2.4 (IO4)
TX: TP_TX.TP, U2.25 (TXD0/GPIO16)
USB_D+: D1.1 (I/O1_1), U2.14 (IO13)
USB_D-: D1.3 (I/O2_1), U2.13 (IO12)
VBAT: C2_BAT.1, MCP73831.3 (VBAT), Q1.3 (D), TP3.TP, U4.2 (CELL), U4.3 (VDD)
VBUS: C1_BAT.1, C4_USB.1, C5_USB.1, CHG_LED.A, D1.5 (VBUS), D2.2 (ANODE), MCP73831.4 (VIN), PFMF.050.1.2, Q1.1 (G), R1_PWRUSB.2, TP14.TP
VRTC: C8.1, C10_SUPERCAP.1, R_CAPACITOR.2, U3.14 (VBAT)
VUSB: J2.A4, J2.A9, J2.B4, J2.B9, PFMF.050.1.1

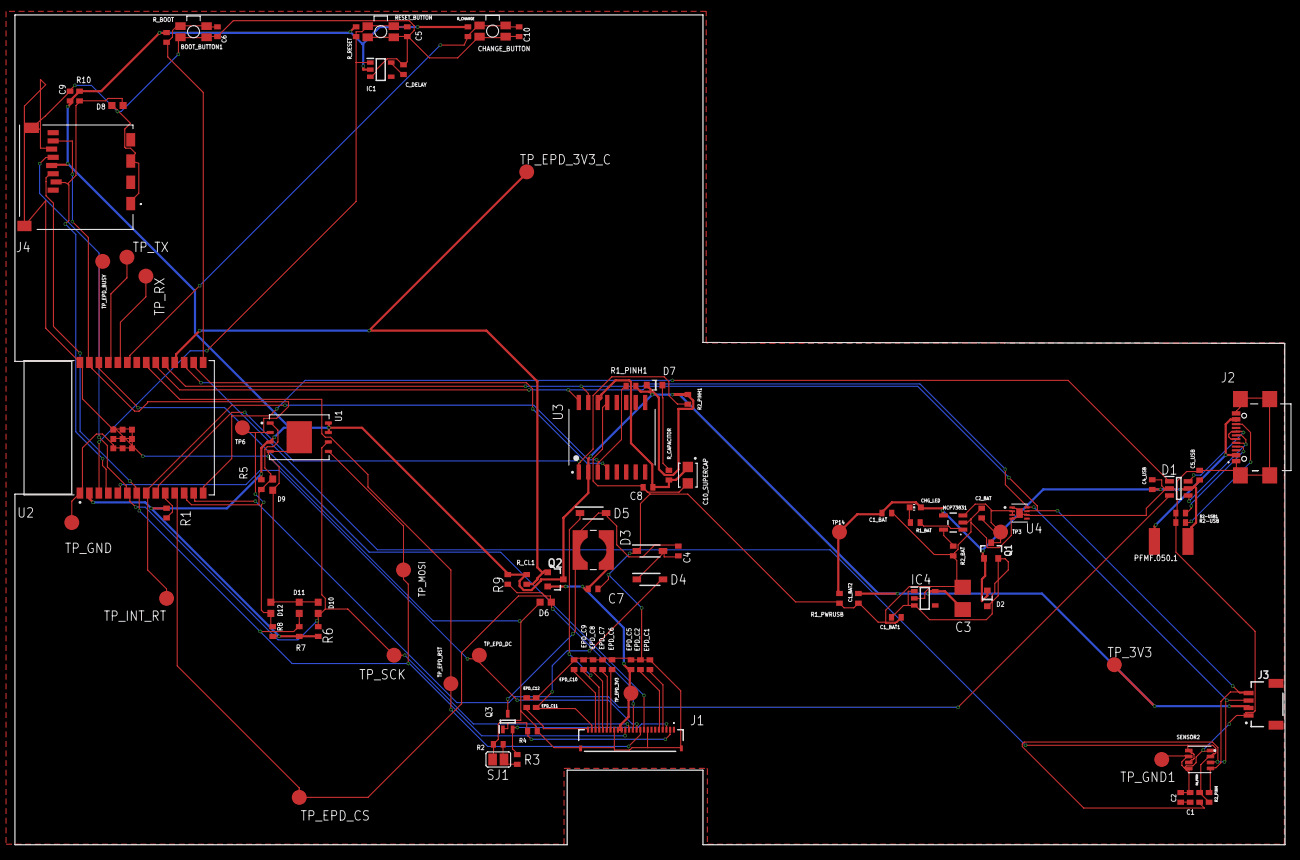
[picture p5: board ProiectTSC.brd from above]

Board: 2 copper layers, 170.2 x 111.2 mm, 103 parts (0 on the bottom side), 56 nets.

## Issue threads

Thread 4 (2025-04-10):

Nume componente pcb

d-florin03, 2025-04-10:
Nu e necesar sa le schimbi marimea si directia la fiecare, le poti lasa la aceeasi marime si aliniate toate la fel, incat nu se inghesuie cu alte componente

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

Closed 2025-04-11.

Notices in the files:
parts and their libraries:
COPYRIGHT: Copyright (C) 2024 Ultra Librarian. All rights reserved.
